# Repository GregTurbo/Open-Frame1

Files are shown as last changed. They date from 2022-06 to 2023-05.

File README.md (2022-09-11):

# Open-Frame1
Open F1 logo stroke mode
An open-source rectangle hardware project for smash, prioritizing ease of assembly and cost.

[Announcement/Overview video](https://youtu.be/RbpOA7Az5DE)

[Example build guide by Crane](https://youtu.be/w4r5CNIimU0)

[Arte's code (pico-rectangle)](https://github.com/JulienBernard3383279/pico-rectangle)

[USB-C to GC cables](https://frame1.gg/collections/all/products/extra-usb-c-to-gamecube-wii-cable)

### Overview
Currently, this project contains the files necessary to create your own Frame1 Light near-equivalent PCB. The files to get this PCB made with parts soldered on are already compiled for you (see: Fabrication Files), but the original schematics are also here if you want to make changes.

The boards are compatible with Rev 1 Heavy and Rev 1/2 Light cases (to be sold in waves on the Frame1.gg website). Switch plate files are included for those who want to design their own case, but full files/guides for creating your own case are planned.

# The Board
whole board
### Overview
In desktop computer terms, the Rapberry Pico is your CPU, and the OF1 PCB is the motherboard. It just feeds power to the Raspberry Pico, routes the USB signal, and connects your switches to the correct pins. 

To accomplish all 3 of these tasks, you will have multiple options. The options you pick will largely depend on budget and level of soldering experience.

## Your Options
- To solder the pico to the board, you can use pin headers or solder the pico straight to the surface. If you use the pin headers, the USB connection will need to be routed via a cable. If you surface mount the pico, you will need to solder in the USB pads on the surface of the pico through the back of the OF1 board (see: Example Builds).
- A surface mount diode can be placed by JLC, but there's also a footprint for a through-hole diode. The through-hole one is easier to solder in if you're doing it yourself. Only use one. Do not populate both.
- You can use Kailh hotswap switches or solder the switches in directly.

Other than the pico, the OF1 board houses 4 main components, and only 2 are mandatory: 
- The main type-c port
- a diode
- a secondary internal type-c port (optional, used to more easily routing the usb signal from the pico to the main port)
- Hotswap sockets
board overview

I would recommend having them assembled via a 3rd party assembly service such as JLC, as type-c ports can be difficult and time-consuming.

## Example Builds

These are examples of the main paths you can take when making a board. All of them assume a board assembled through a 3rd party with at least the main type-c port and diode soldered on already. 

The choice of connecting kailh hotswap sockets vs soldering switches in directly doesn't depend on any of the other assembly choices. The sockets are cheap, and take just as many solder joints to complete as soldering in switches directly. For this reason, I will also be assuming hotswap sockets are be used. It's the option that makes the most sense for the majority of people.

### The Easy Build
This build prioritizes ease of assembly above everything. I highly recommend this path for beginners to soldering. It has the second shortest build time, and the least potential for error. Requires the internal secondary type-c connector.
easy mode

The 3 main steps are:
- Solder in the pico via pin headers (link to that section of the crane vid here)
- Connect a USB micro-b to type-c cable from the pico to the port on the board. (These can be found in 6" lengths on sites like Amazon)
- Solder in hotswap sockets

### The Fast & Cheap build
This build is the cheapest, and assuming no errors, fastest build. Recommended for those with a lot of soldering experience
expert mode

The 3 main steps are:
- Solder the pico on the surface of the OF1 board using the pads and castellated edges on the pico. Alignment is extremely important. You can use the pico's corner holes as a visual guide. Or, you can use something like a matching set of M2 screws and nuts to physically align and hold the board in place (At the time of writing I have not personally tried screws but it should work).
- To connect the USB from the pico to the main board, you need to add solder to these holes on the back of the OF1 board. They make contact with the USB pads on the back of the pico. You may need to pre-tin the test pads before-hand, but your mileage may vary
- Solder in hotswap sockets

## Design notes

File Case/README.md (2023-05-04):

## Open Source Case Options

There are a couple open source case options available when trying to enclose your of1 pcb. These are listed below

# Bjart's OFOF1

https://github.com/rana-sylvatica/OFOF1

# Davy's 3d printable cases

https://www.printables.com/model/394573-openframe1-full-case \
https://www.printables.com/model/394572-openframe1-case-glued

# Ed's 3d printable case

https://www.thingiverse.com/thing:5604960

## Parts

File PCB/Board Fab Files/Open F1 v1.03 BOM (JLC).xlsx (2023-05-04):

Designator | Description | Footprint | LCSC Part Number | Manufacturer Part Number | Comment
D2 | SOD-123 Schottky Diode | SOD-123 | C130880 | MBR120LSF | if you want through hole, populate D1 instead
J2 | USB TYPE-C 24P Receptacle | TYPE-C 24P QCHT | C456013 | TYPE-C 24P QCHT
J5 | USB 2.0 Female Type-C USB 16P | TYPE-C 16P SMD | C2837092 | GT-USB-7010 | Optional
R2, R4 | 5.1K Ohm | _0603 | C881139 |  | If you want through hole, populate R1 and R3 instead

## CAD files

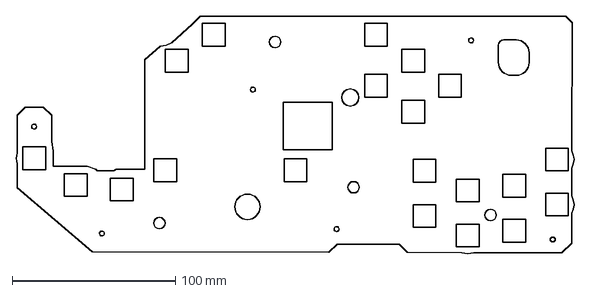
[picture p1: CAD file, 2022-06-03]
Case/Switch Plate.dxf
342.3 x 145.6 mm

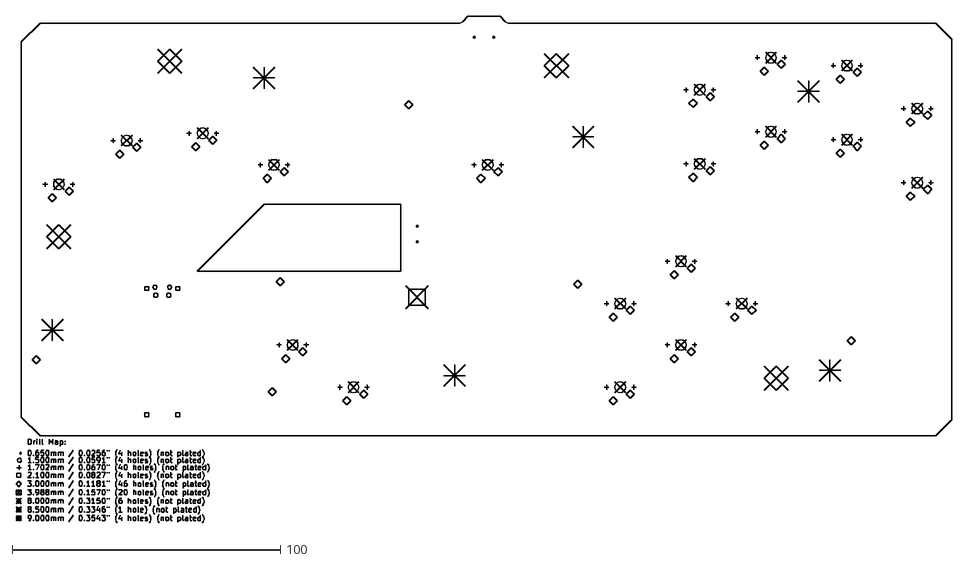
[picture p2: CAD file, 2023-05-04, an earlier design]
PCB/Board Schematics/Kicad_schematics_pico (recommended)/OF1 v1.02/OF1 v1-NPTH-drl_map.dxf
349.0 x 188.8

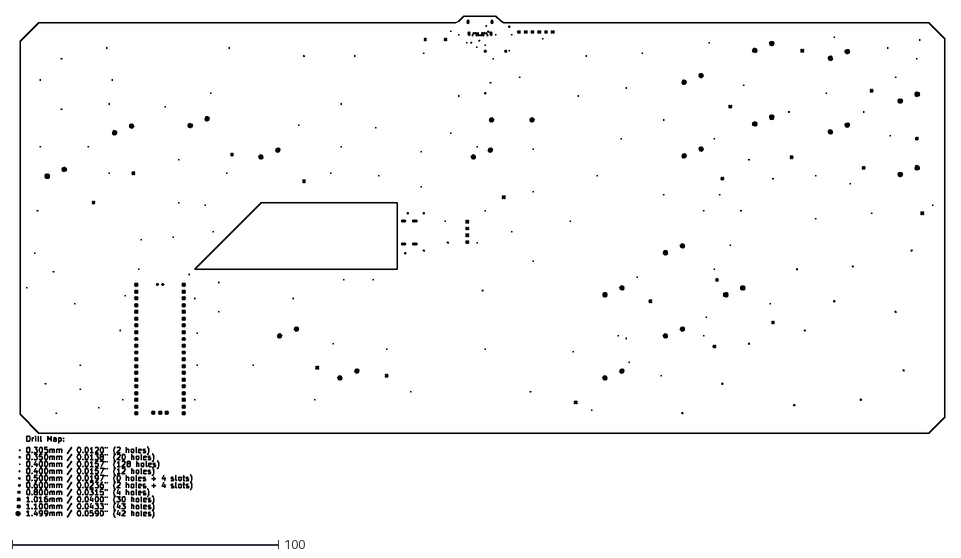
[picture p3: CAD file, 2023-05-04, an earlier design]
PCB/Board Schematics/Kicad_schematics_pico (recommended)/OF1 v1.02/OF1 v1-PTH-drl_map.dxf
348.5 x 188.4

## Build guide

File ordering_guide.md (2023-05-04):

# Open-Frame1 Ordering Guide
First screen you'll upload the fabrication files. Just upload the .zip file located /PCB/Board Fab Files/. At the bottom of this screen JLC asks if you want them to do any smt assembly which you should select.

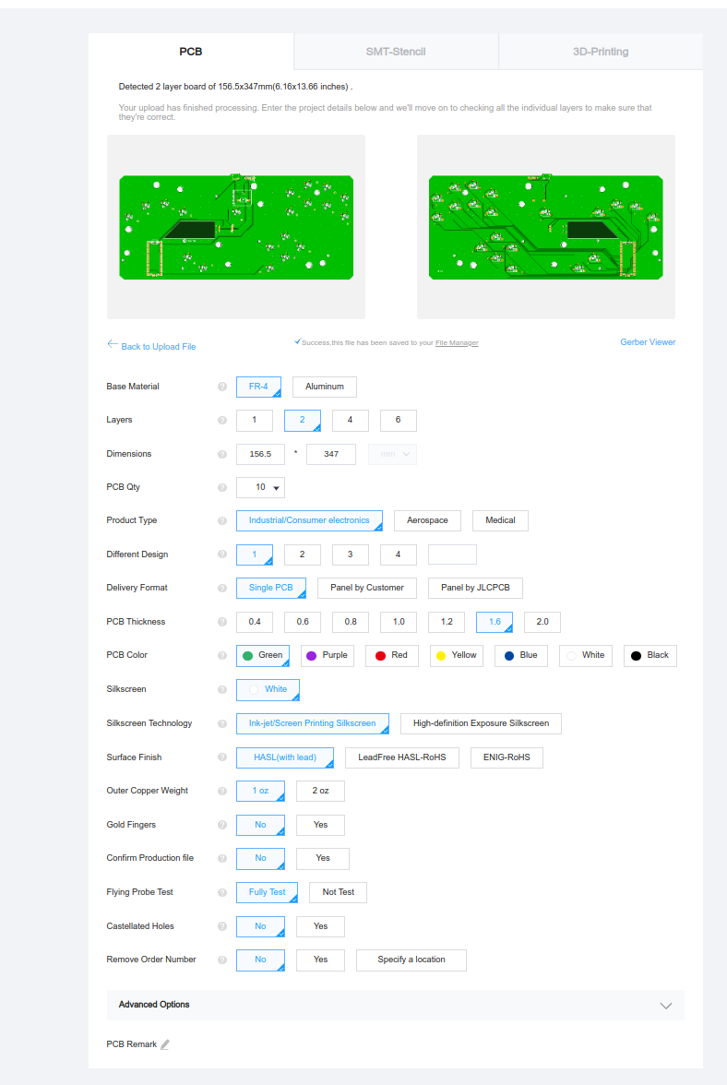
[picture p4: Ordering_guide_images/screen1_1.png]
Screen1_1
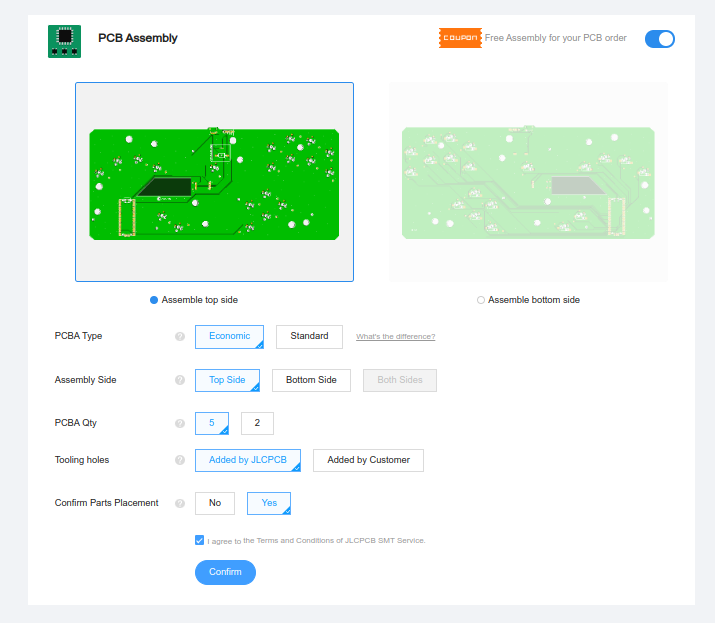
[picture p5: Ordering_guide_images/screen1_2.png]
Screen1_2


Next screen they ask for the BOM (Bill of Materials) spreadsheet and the CPL (tells them where to place the components) spreadsheet. Upload the 2 .xlsx files located in the same folder as the .zip.

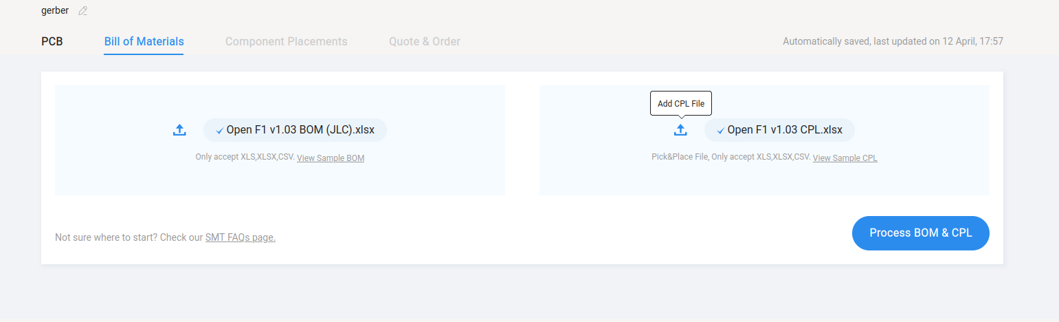
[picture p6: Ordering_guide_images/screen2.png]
Screen2_1


The next screen will ask which components you want them to assemble. The 24 pin connector is pretty much mandatory as you can't do it without a hot air station. The other 4 components are convenient.

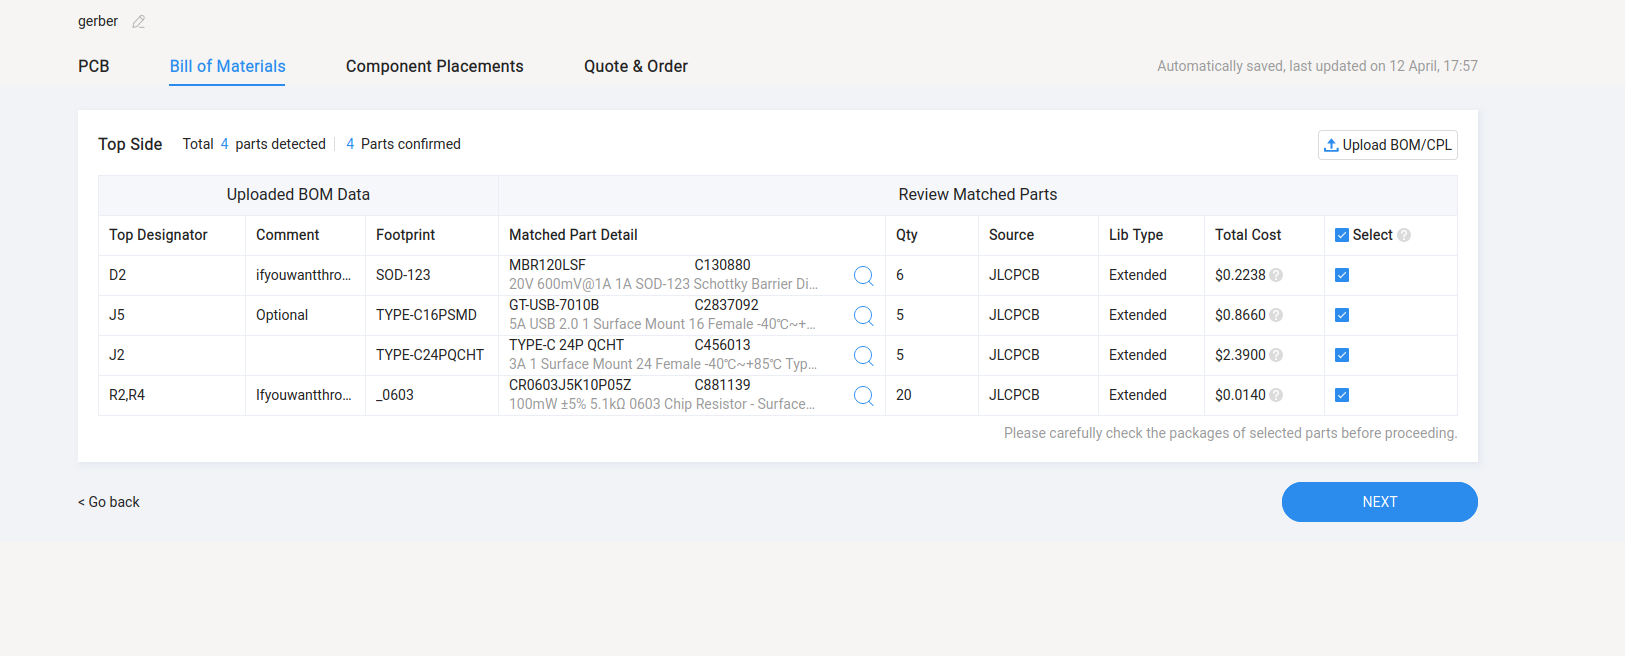
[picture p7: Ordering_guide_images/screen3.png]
Screen3_1


The next screen shows you a preview and from there you should be good to order. Initial renders of the part placement will likely be incorrect. THIS IS OK! If you selected yes to "confirm parts placement" on screen 1 jlc will reach out via email and fix the placements. You will need to confirm that the parts are correct similar to the image included.

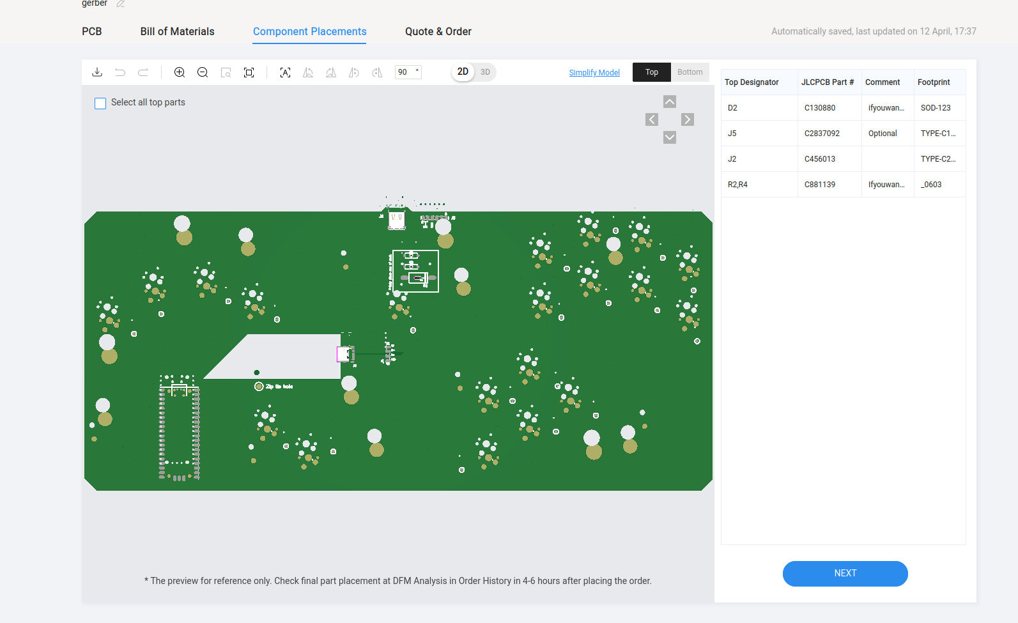
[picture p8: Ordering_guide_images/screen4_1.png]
Screen4_1
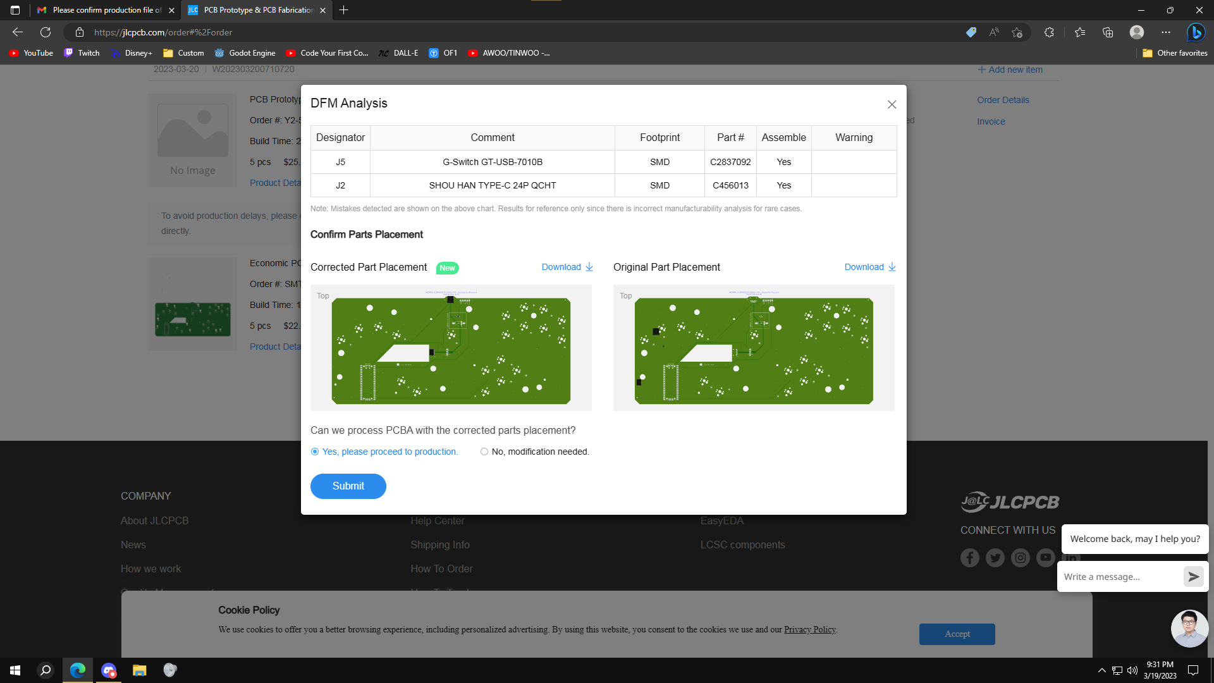
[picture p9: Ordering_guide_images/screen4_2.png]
Screen4_2


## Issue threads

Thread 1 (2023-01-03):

Add instructions for ordering PCBs with assembly to README

Soundtoxin, 2023-01-03:
Thank you for Open-Frame1, it seems very exciting. I think the PCB ordering process is confusing for new users, so some additional info here would be a big help. The build guide video in the readme does not cover this part of the process. I'm hoping to build a few of these controllers and give some to friends in addition to using one myself if I can figure this out.

Something like you see in the README here would be good: https://github.com/rana-sylvatica/circle-keycaps

@rana-sylvatica has put a detailed guide for getting some keycaps from JLC / jlcpcb.com. I would like to use the same site to order some PCBs. The build guide video recommends having them solder on the USB-C port for you since that part is difficult, and possibly also the schottky diode while you're at it, but this process requires a BOM file and CPL file.
For the main target audience (gamers from the FGC) of these controllers, I think this will be difficult and initimidating. Many of them may not have dipped their toes into the DIY electronics world before now. The build guide video does a good job of being applicable to beginners by even recommending a starter soldering iron, solder, and other tools. If we can just improve the PCB ordering part of the process I think a lot more people would be able to actually build these controllers.

I understand that not everyone may order through JLC depending on their geography, but hopefully covering how to get a BOM and CPL file would be enough to help people using other sites as well, and JLC could just serve as an example.

Soundtoxin, 2023-01-04:
I was also referred to the Phob guide for a different controller:

https://github.com/PhobGCC/PhobGCC-doc/blob/main/For_Makers/Phob2_Ordering_Guide.md

However for that controller they've supplied the needed files on their releases page for assembly, so they don't cover how else to get them, and the files would of course be different for the Frame1. I'm starting to get the feeling that the necessary knowledge to complete this is locked away in some Discord. As many people don't use Discord, it would be nice to have it out in the open with everything else.

Soundtoxin, 2023-01-05:
I finally found that the needed files were in the repo, just not the releases page. I would recommend adding:
https://github.com/GregTurbo/Open-Frame1/blob/main/PCB/Board%20Fab%20Files/Open%20F1%20v1%20BOM%20(JLC).xlsx
https://github.com/GregTurbo/Open-Frame1/blob/main/PCB/Board%20Fab%20Files/Open%20F1%20v1%20CPL.xlsx

to the releases page similar to how PhobGCC provides the equivalent files on their releases page.

I'm also finding the process of having a case made rather confusing, but that might be outside the scope of this repo.

I have come across at least two options:
https://github.com/rana-sylvatica/OFOF1
and
https://www.thingiverse.com/thing:5445251

It's not totally clear how many parts actually need to be printed and put together and where to get them all. OFOF1 has standoffs and panels while the thingiverse has "Full_body" and "Full_backplate".
Again I think an additional guide is in order for just wrangling together all the parts and ordering them in the first place. In this case maybe both the above links are valid options, so they could just be explained better within the guide and clarify which parts you need to have printed to have a full enclosure in the end. My thoughts at this point are that I may just need to get most of what I think I need in-hand and then maybe during assembly I'll realize if something is missing, and then I'll end up waiting a few more days to get any parts I may be missing.
A guide could also discuss pros and cons of resin vs nylon for some of these parts and ways to make some things more affordable. I was a bit shocked at the shipping costs from JLC PCB (I'm in the US). For the PCBs I was paying almost exactly as much for shipping as I was for the boards. There were some cheaper shipping options but none significantly cheaper, so it didn't really seem worth a possible worse experience than DHL. To make matters worse, you can't order 3D prints and PCBs together from JLC, so I would have to eat that massive shipping cost a second time. I've held off ordering the 3D prints for now in case I can find a cheaper way to have those parts made (and because it's still unclear for sure which parts I do need to have made).

Soundtoxin, 2023-02-06:
Just an update, the linked thingiverse case in the previous post has another (newer) variant that you can print at home in smaller pieces and then glue together. I've had mostly pretty good luck with using an Ender 3 v2 with PLA+ filament and then glueing with superglue. I would recommend this version as it can be printed without supports and is the most up-to-date version of the case.

https://www.thingiverse.com/thing:5632408

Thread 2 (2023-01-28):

Different MCU and MCU placement for future revisions

Soundtoxin, 2023-01-28:
I've been looking into the Flatbox rev5[0] recently and thinking they did certain things better than the Open-Frame1 board. In particular they chose an MCU with a USB-C port and put it in the top middle of the board so you can just plug right into it. No hassle of soldering a USB-C port or ordering a board with assembly. This is similar to how a lot of mechanical keyboard builds are handled as well. They use the RP2040-Zero[1], which is somewhat niche, I could only find it on waveshare and not adafruit. There are some other RP2040-based boards with USB-C boards, though, such as the Feather[2] boards from adafruit. Something like that might simplify the build a lot. It feels kinda jank having a cable in there to reroute the USB, and it kinda bulges and makes it hard to get the case together.

The Feather board I linked as an example does cost more than the Pi Pico currently used, however if you add in the cost of a cable to go from microUSB B to USB-C that you won't need anymore, it doesn't look so bad.

It's possible I'm overlooking part of the design. Maybe the placement is to best fit an optional Brook add-on board without getting in the way of the buttons. I know there's a label saying you can use some of the holes for a zip-tie. I haven't done any of that in my builds so far.

[0] https://github.com/jfedor2/flatbox/tree/master/hardware-rev5
[1] https://www.waveshare.com/rp2040-zero.htm
[2] https://www.adafruit.com/product/4884

Soundtoxin, 2023-02-10:
Regarding placement, I think it's also worth considering designing the PCB to have the controller on the bottom instead of the top of the PCB. This would give easier access to the BOOTSEL button in case of flashing bad firmware and not being able to use a button combo to get into this mode. Currently (at least with the [case](https://www.thingiverse.com/thing:5632408) I used) you have to remove every single switch, remove the bottom cover, and pull out the PCB if you need to get at the BOOTSEL button. If the microcontroller were on the bottom instead, you'd only need to remove the bottom cover to get at the buttons, and you could leave your switches in.

Soundtoxin, 2023-06-15:
There's also a TP6 pad on the bottom of the Pico you can short to ground which can act as BOOTSEL. A couple well-placed holes in the Open-Frame1 PCB, or even better, a place to solder a new button to those bits for bottom-access would be another good option.
Recently I keep having some of my buttons (mostly the up button on the far right) pop out (using kailh hotswap sockets) during play or transport, and there's a decent chance of the pins bending when re-inserting. I don't want to solder or glue in these switches since that would lock off easy access to BOOTSEL in case of a firmware emergency. If I had more convenient access to that mode from the bottom, I would be able to put a dab of hot glue or something on my switch pins from the bottom to hold them in better without worrying that I'll have to remove every switch later to fix the firmware (not hypothetical, by the way, I put GP2040-CE on an Open-Frame1 once to see if PS3/4 support was better than in HayBox and the button mappings were a mess so I couldn't figure out what to press to flash it again and had to tear it apart).

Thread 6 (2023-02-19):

Alternate links for USB-C to GC cable

Soundtoxin, 2023-02-19:
I think we need an alternate source for the cables in the readme. I ordered one from the Frame1 site over a month ago, and have heard basically nothing. They show as in-stock, so I assumed they were already made and would just be shipped out. Not sure what the deal is. I managed to get a cable from the B0xx site in under a week (ordered fewer *and* they cost a little more, though), and they also have the USB-C to N64 cables, so they should be listed as a source instead or additionally. I also think a guide for making your own cables would be good to have linked in the readme to reduce these points of failure in sourcing such an important part. I don't know of a good guide, hopefully someone else does. Otherwise one may need to be written/recorded.

GregTurbo, 2023-02-19:
Your order includes 2 things that are not currently shipping (brook installation kits that are only for the soon-to-be released Frame1 wave). Your order would have shipped weeks ago otherwise

Soundtoxin, 2023-02-19:
Thank you for the additional info, Greg. I still really do think it may be worth listing multiple sources / DIY methods for the cables in the future (so not sure the issue should be closed), but I'm glad to have cleared up my particular case now.

Closed 2023-02-19.

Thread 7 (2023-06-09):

Could I use a wire instead of a Schottky DIODE?

zerinsakech, 2023-06-09:
The instructions make it seem like a Diode is needed regardless whether you use the additional Connections (for direct GameCube controller port I assume?) Since most case designs for the Open1 don't seem to include this extra port, and it's cheaper/easier to make a USB C to GameCube cable instead of designing a case with the port, can we just wire up a solid wire (0 ohm) instead of a DIODE? I'm trying to save money and costs so wondering if this is a good alternate instruction to add to the Readme?

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

GregTurbo, 2023-06-09:
There is no second port, the usb-c connector handles USB or GCC connections with their respective cables. The unpopulated headed on the right there is just for the sake of mods or troubleshooting.

If you're ONLY ever going to use USB, and don't plan on using a GameCube connection, DO NOT use a wire. Instead, just don't populate the diode at all. USB will work fine and you can always add the diode later anyway

zerinsakech, 2023-06-09:
Thanks for the clarification!

Closed 2023-06-09.

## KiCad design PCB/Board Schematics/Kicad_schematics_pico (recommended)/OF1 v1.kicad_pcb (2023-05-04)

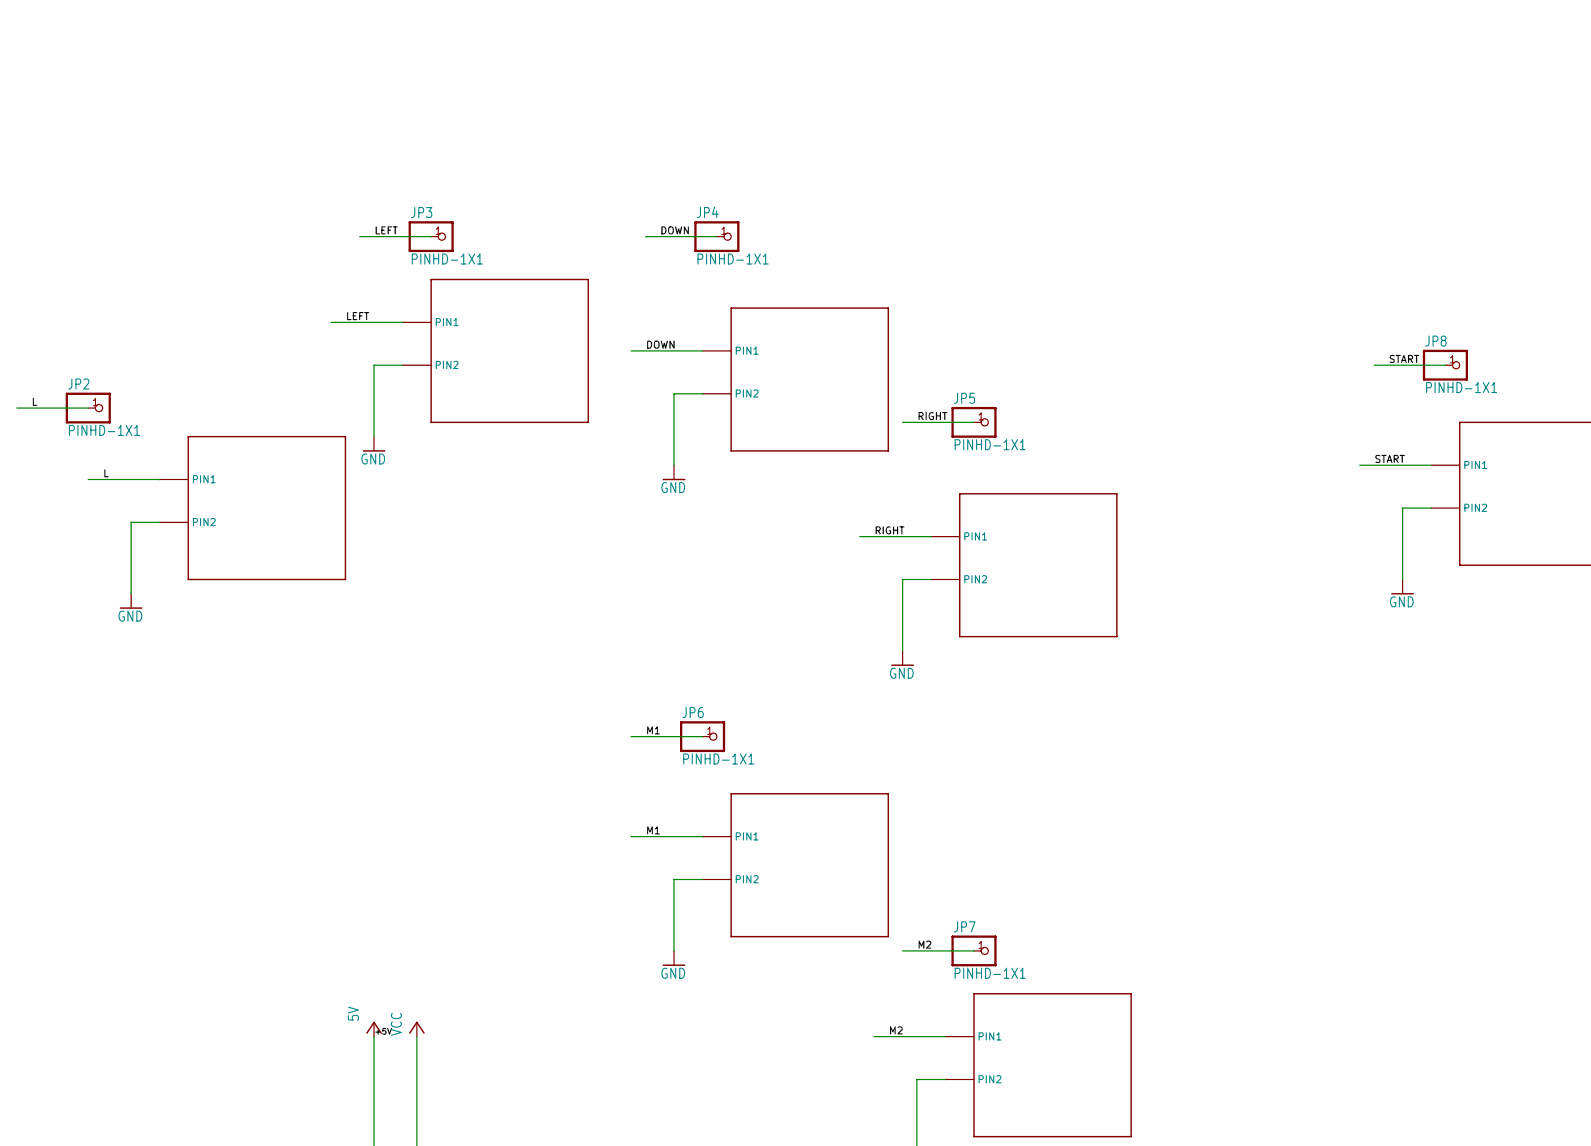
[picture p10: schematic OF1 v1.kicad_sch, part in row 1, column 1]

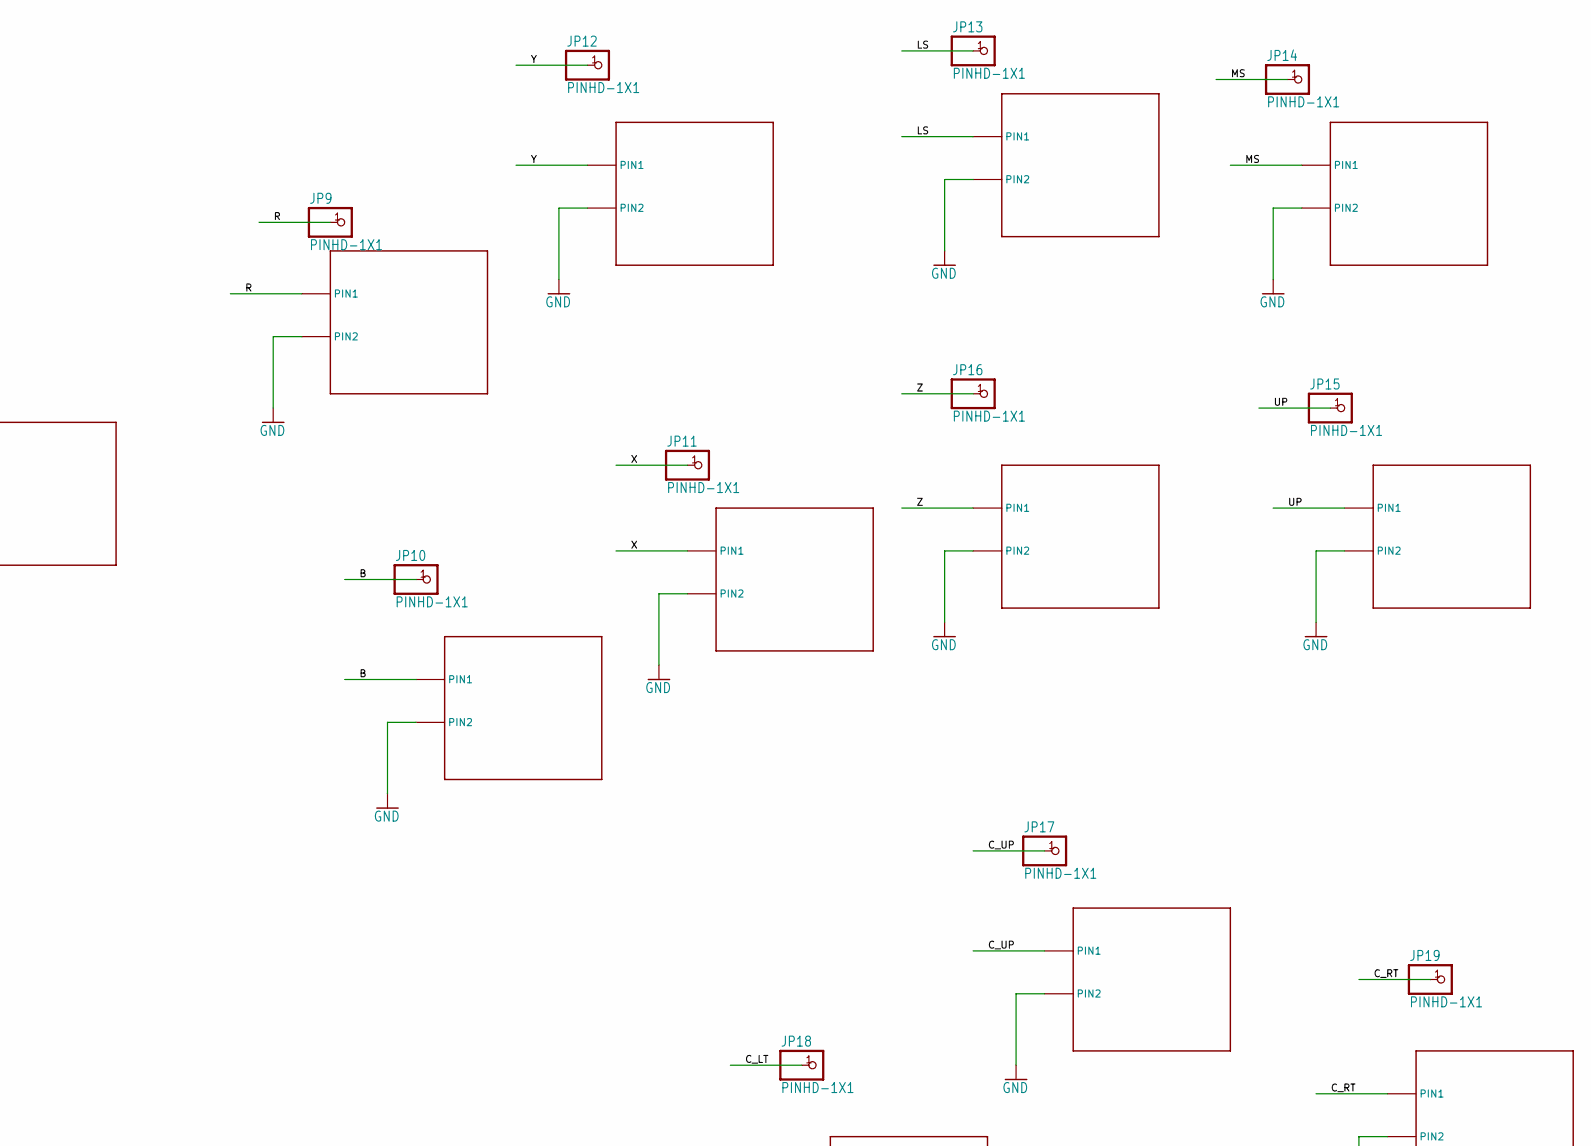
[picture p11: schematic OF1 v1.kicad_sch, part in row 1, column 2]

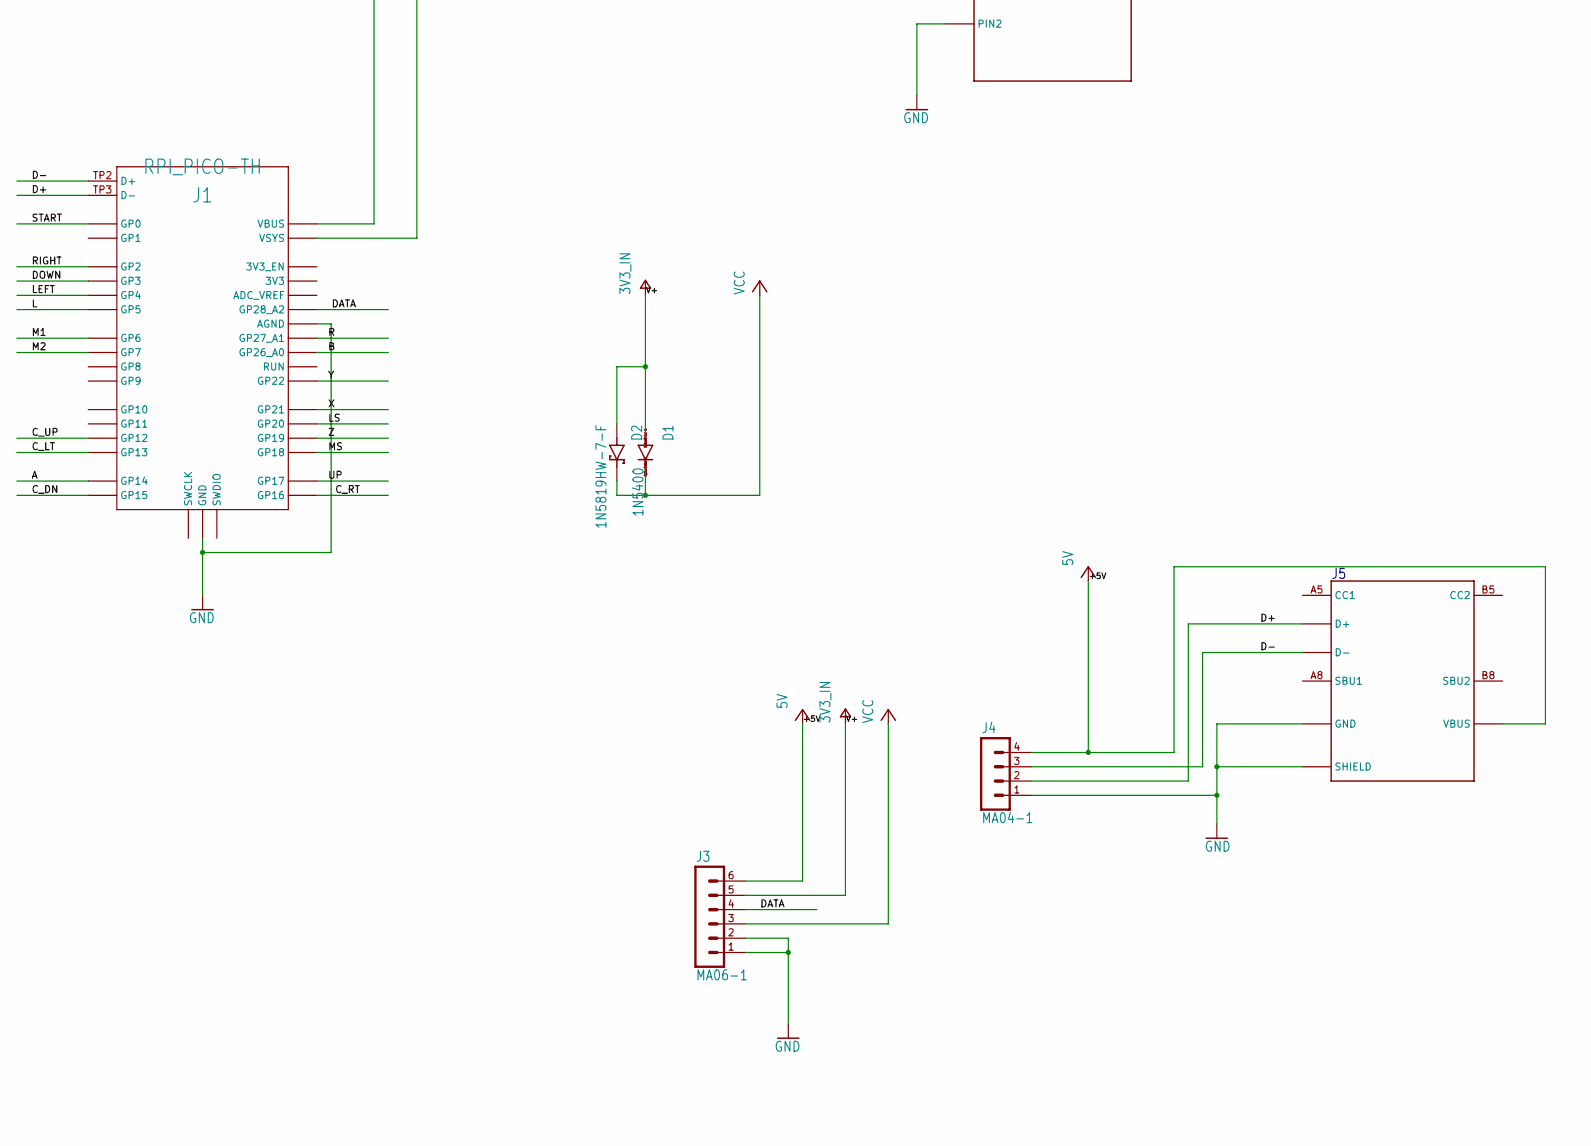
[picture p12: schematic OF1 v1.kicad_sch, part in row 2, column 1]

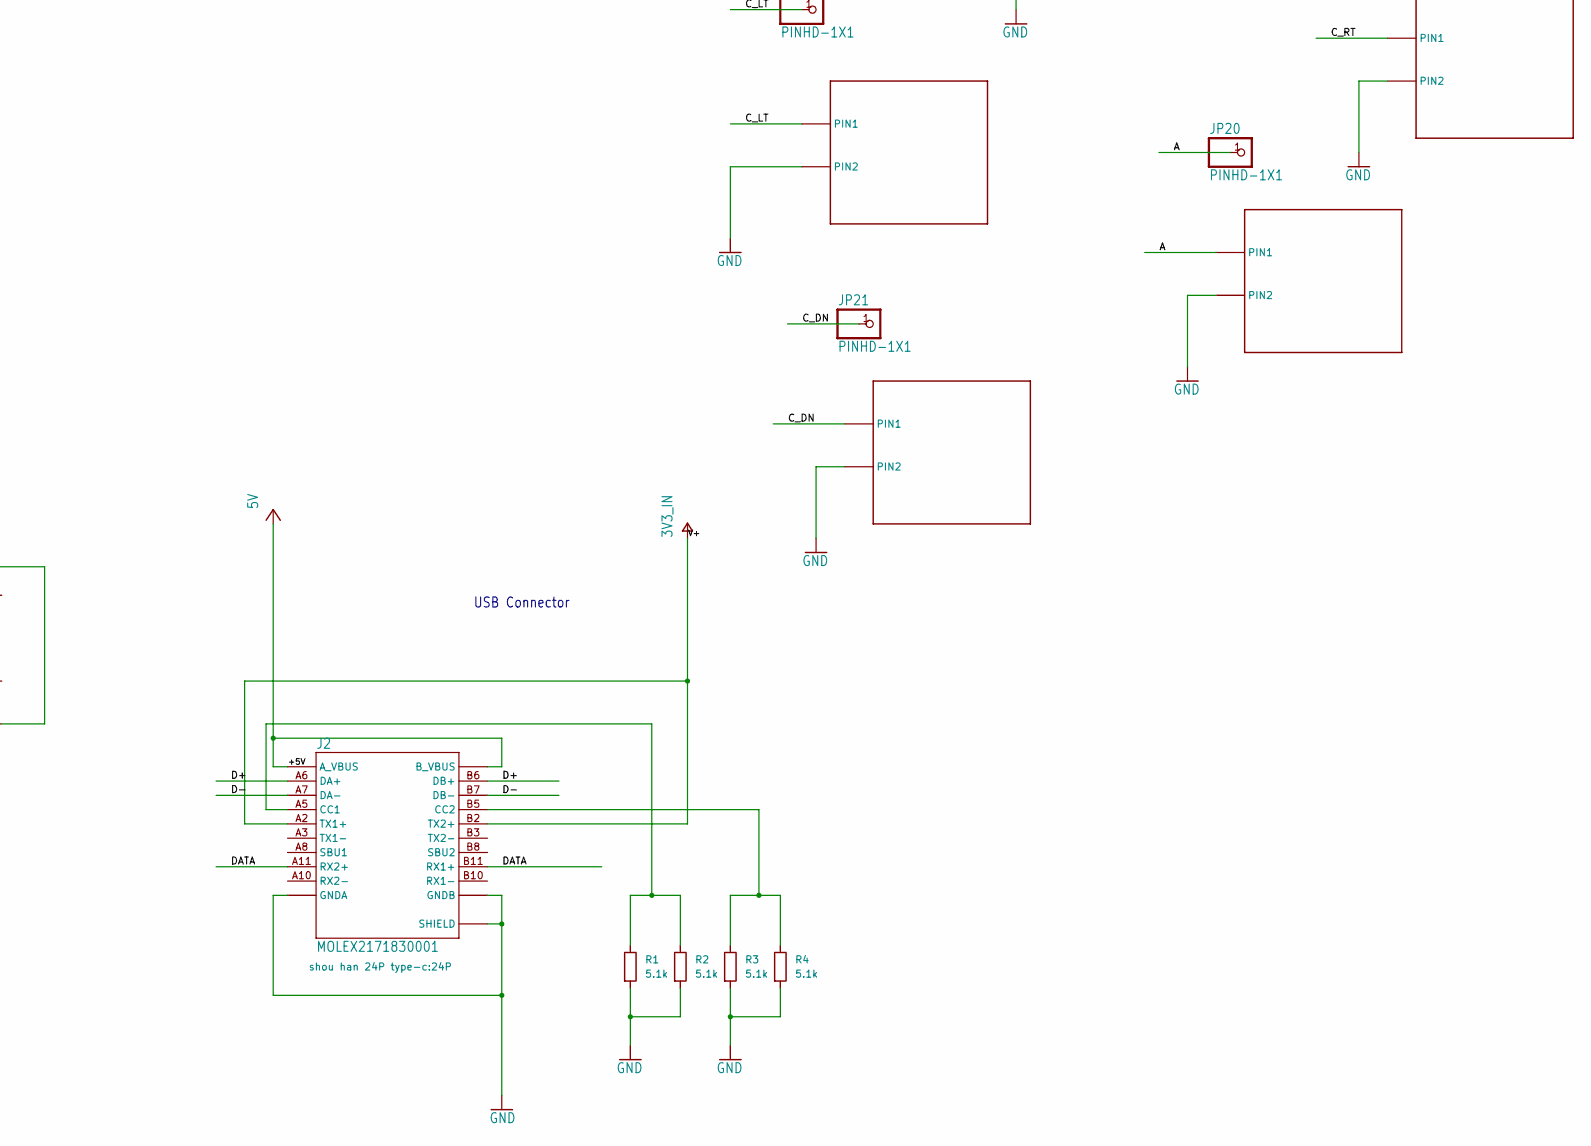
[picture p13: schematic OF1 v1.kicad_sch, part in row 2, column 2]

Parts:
D1: 1N5400; DO201-15
D2: 1N5819HW-7-F; SOD3715X145N
J1: RPI_PICO-TH; RPI_PICO_TH
J2: MOLEX2171830001; 24P
J3: MA06-1
J4: MA04-1
J5: GT-USB-7010; 16P
JP2, JP3, JP4, JP5, JP6, JP7, JP8, JP9, JP10, JP11, JP12, JP13, JP14, JP15, JP16, JP17, JP18, JP19, JP20, JP21: PINHD-1X1; 1X01
R1, R3: 5.1k; R_Axial_DIN0207_L6.3mm_D2.5mm_P7.62mm_Horizontal
R2, R4: 5.1k; R_0603_1608Metric
U$1, U$2, U$4, U$5, U$6, U$7, U$8, U$9, U$10, U$11, U$12, U$13, U$14, U$15, U$16, U$17, U$18, U$19, U$20, U$21: MX-B; MX-BOTH

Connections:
+5V: J1.VBUS, J2.A4 (A_VBUS), J2.A9 (A_VBUS), J2.B4 (B_VBUS), J2.B9 (B_VBUS), J3.6, J4.4, J5.A4/B9 (VBUS), J5.B4/A9 (VBUS)
/A: J1.GP14, JP20.1, U$20.P$2 (PIN1), U$20.P$3 (PIN1)
/B: J1.GP26_A0, JP10.1, U$13.P$2 (PIN1), U$13.P$3 (PIN1)
/C_DN: J1.GP15, JP21.1, U$21.P$2 (PIN1), U$21.P$3 (PIN1)
/C_LT: J1.GP13, JP18.1, U$18.P$2 (PIN1), U$18.P$3 (PIN1)
/C_RT: J1.GP16, JP19.1, U$19.P$2 (PIN1), U$19.P$3 (PIN1)
/C_UP: J1.GP12, JP17.1, U$17.P$2 (PIN1), U$17.P$3 (PIN1)
/D+: J1.TP3 (D-), J2.A6 (DA+), J2.B6 (DB+), J4.2, J5.A6 (D+), J5.B6 (D+)
/D-: J1.TP2 (D+), J2.A7 (DA-), J2.B7 (DB-), J4.3, J5.A7 (D-), J5.B7 (D-)
/DATA: J1.GP28_A2, J2.A11 (RX2+), J2.B11 (RX1+), J3.4
/DOWN: J1.GP3, JP4.1, U$4.P$2 (PIN1), U$4.P$3 (PIN1)
/L: J1.GP5, JP2.1, U$1.P$2 (PIN1), U$1.P$3 (PIN1)
/LEFT: J1.GP4, JP3.1, U$2.P$2 (PIN1), U$2.P$3 (PIN1)
/LS: J1.GP20, JP13.1, U$11.P$2 (PIN1), U$11.P$3 (PIN1)
/M1: J1.GP6, JP6.1, U$6.P$2 (PIN1), U$6.P$3 (PIN1)
/M2: J1.GP7, JP7.1, U$7.P$2 (PIN1), U$7.P$3 (PIN1)
/MS: J1.GP18, JP14.1, U$12.P$2 (PIN1), U$12.P$3 (PIN1)
/R: J1.GP27_A1, JP9.1, U$9.P$2 (PIN1), U$9.P$3 (PIN1)
/RIGHT: J1.GP2, JP5.1, U$5.P$2 (PIN1), U$5.P$3 (PIN1)
/START: J1.GP0, JP8.1, U$8.P$2 (PIN1), U$8.P$3 (PIN1)
/UP: J1.GP17, JP15.1, U$16.P$2 (PIN1), U$16.P$3 (PIN1)
/X: J1.GP21, JP11.1, U$14.P$2 (PIN1), U$14.P$3 (PIN1)
/Y: J1.GP22, JP12.1, U$10.P$2 (PIN1), U$10.P$3 (PIN1)
/Z: J1.GP19, JP16.1, U$15.P$2 (PIN1), U$15.P$3 (PIN1)
GND: J1.AGND, J1.GND@1 (GND), J1.GND@2 (GND), J1.GND@3 (GND), J1.GND@4 (GND), J1.GND@5 (GND), J1.GND@6 (GND), J1.GND@7 (GND), J1.GND@8 (GND), J2.A1 (GNDA), J2.A12 (GNDA), J2.B1 (GNDB), J2.B12 (GNDB), J2.SHIELD1 (SHIELD), J2.SHIELD2 (SHIELD), J2.SHIELD3 (SHIELD), J2.SHIELD4 (SHIELD), J3.1, J3.2, J4.1, J5.A1/B12 (GND), J5.B1/A12 (GND), J5.SHIELD1 (SHIELD), J5.SHIELD2 (SHIELD), J5.SHIELD3 (SHIELD), J5.SHIELD4 (SHIELD), R1.2, R2.2, R3.2, R4.2, U$1.P$1 (PIN2), U$1.P$4 (PIN2), U$2.P$1 (PIN2), U$2.P$4 (PIN2), U$4.P$1 (PIN2), U$4.P$4 (PIN2), U$5.P$1 (PIN2), U$5.P$4 (PIN2), U$6.P$1 (PIN2), U$6.P$4 (PIN2), U$7.P$1 (PIN2), U$7.P$4 (PIN2), U$8.P$1 (PIN2), U$8.P$4 (PIN2), U$9.P$1 (PIN2), U$9.P$4 (PIN2), U$10.P$1 (PIN2), U$10.P$4 (PIN2), U$11.P$1 (PIN2), U$11.P$4 (PIN2), U$12.P$1 (PIN2), U$12.P$4 (PIN2), U$13.P$1 (PIN2), U$13.P$4 (PIN2), U$14.P$1 (PIN2), U$14.P$4 (PIN2), U$15.P$1 (PIN2), U$15.P$4 (PIN2), U$16.P$1 (PIN2), U$16.P$4 (PIN2), U$17.P$1 (PIN2), U$17.P$4 (PIN2), U$18.P$1 (PIN2), U$18.P$4 (PIN2), U$19.P$1 (PIN2), U$19.P$4 (PIN2), U$20.P$1 (PIN2), U$20.P$4 (PIN2), U$21.P$1 (PIN2), U$21.P$4 (PIN2)
unnamed: J2.A5 (CC1), R1.1, R2.1
unnamed: J2.B5 (CC2), R3.1, R4.1
V+: D1.A, D2.A, J2.A2 (TX1+), J2.B2 (TX2+), J3.5
VCC: D1.C, D2.C (K), J1.VSYS, J3.3

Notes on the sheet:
USB Connector

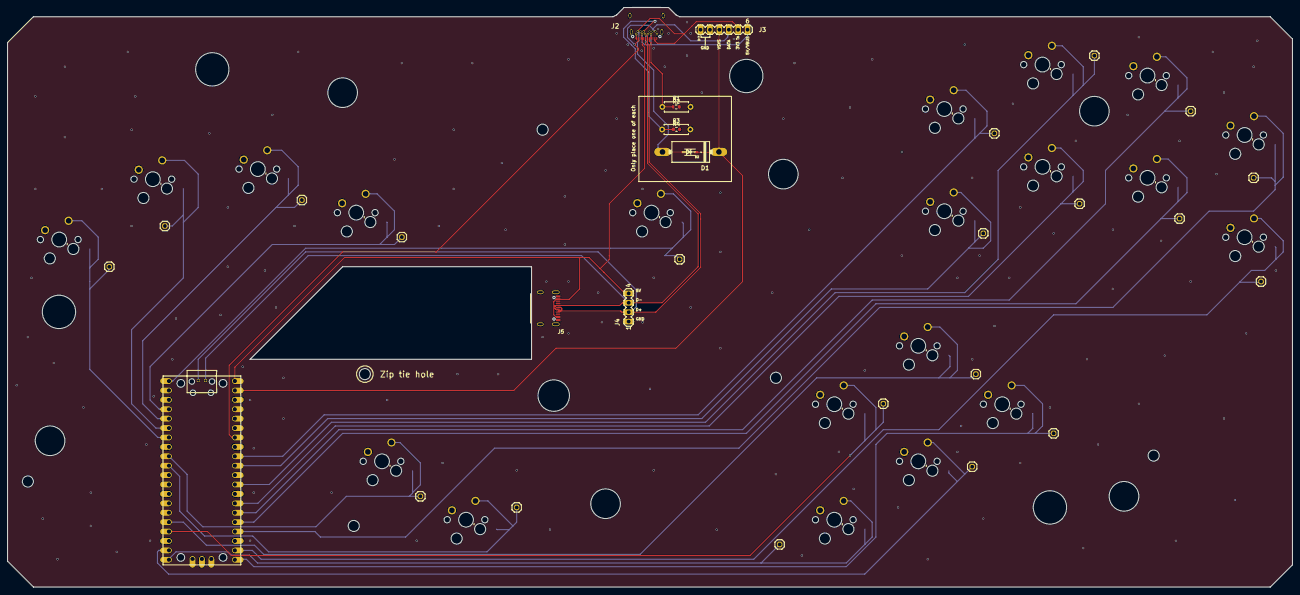
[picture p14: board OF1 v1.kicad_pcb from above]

Board: 2 copper layers, 347.0 x 156.5 mm, 68 parts (0 on the bottom side), 29 nets.

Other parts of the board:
@HOLE0, @HOLE1, @HOLE2, @HOLE3, @HOLE4, @HOLE5, @HOLE6, @HOLE7, @HOLE8, @HOLE9, @HOLE10, @HOLE11, @HOLE12, @HOLE13, @HOLE14, @HOLE15, @HOLE16: (no value)

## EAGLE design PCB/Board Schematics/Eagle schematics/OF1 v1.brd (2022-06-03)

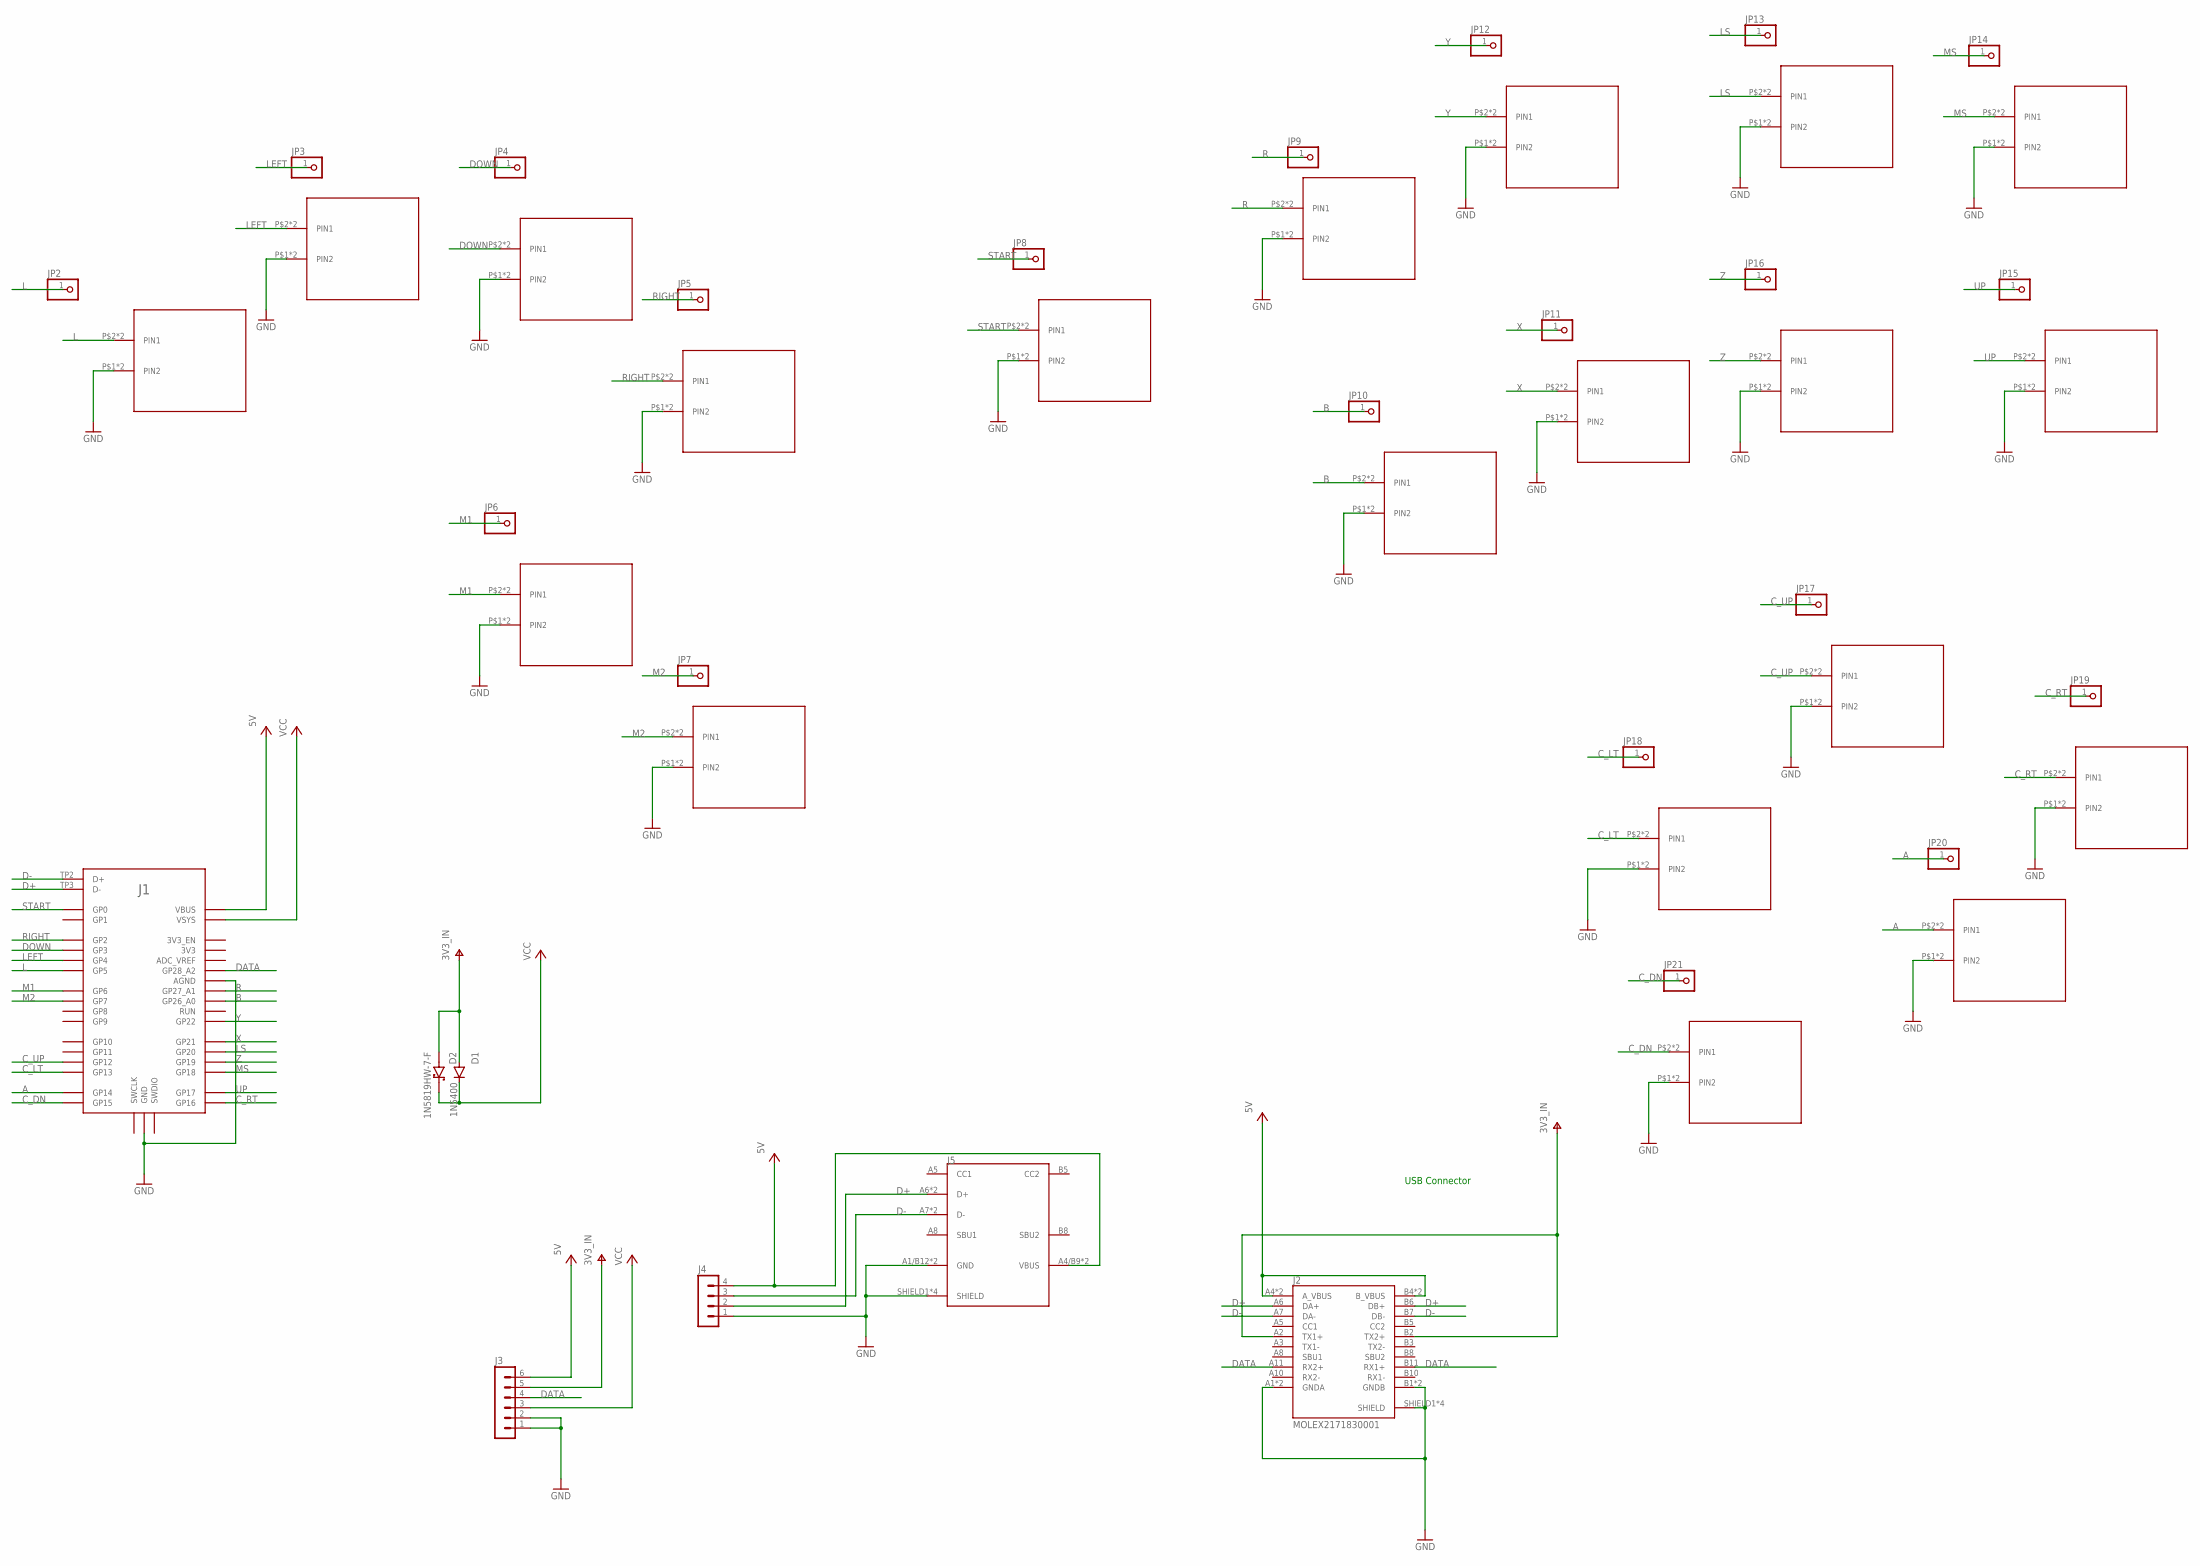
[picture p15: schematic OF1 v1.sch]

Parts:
D1: 1N5400; DO201-15
D2: 1N5819HW-7-F; SOD3715X145N
J1: RPI_PICO-TH; RPI_PICO_TH
J2: MOLEX2171830001; 24P
J3: MA06-1
J4: MA04-1
J5: GT-USB-7010ASV; 16P
JP2, JP3, JP4, JP5, JP6, JP7, JP8, JP9, JP10, JP11, JP12, JP13, JP14, JP15, JP16, JP17, JP18, JP19, JP20, JP21: PINHD-1X1; 1X01
U$1, U$2, U$4, U$5, U$6, U$7, U$8, U$9, U$10, U$11, U$12, U$13, U$14, U$15, U$16, U$17, U$18, U$19, U$20, U$21: MX-B; MX-BOTH

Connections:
+5V: J1.VBUS, J2.A4 (A_VBUS), J2.A9 (A_VBUS), J2.B4 (B_VBUS), J2.B9 (B_VBUS), J3.6, J4.4, J5.A4/B9 (VBUS), J5.B4/A9 (VBUS)
A: J1.GP14, JP20.1, U$20.P$2 (PIN1), U$20.P$3 (PIN1)
B: J1.GP26_A0, JP10.1, U$13.P$2 (PIN1), U$13.P$3 (PIN1)
C_DN: J1.GP15, JP21.1, U$21.P$2 (PIN1), U$21.P$3 (PIN1)
C_LT: J1.GP13, JP18.1, U$18.P$2 (PIN1), U$18.P$3 (PIN1)
C_RT: J1.GP16, JP19.1, U$19.P$2 (PIN1), U$19.P$3 (PIN1)
C_UP: J1.GP12, JP17.1, U$17.P$2 (PIN1), U$17.P$3 (PIN1)
D+: J1.TP3 (D-), J2.A6 (DA+), J2.B6 (DB+), J4.2, J5.A6 (D+), J5.B6 (D+)
D-: J1.TP2 (D+), J2.A7 (DA-), J2.B7 (DB-), J4.3, J5.A7 (D-), J5.B7 (D-)
DATA: J1.GP28_A2, J2.A11 (RX2+), J2.B11 (RX1+), J3.4
DOWN: J1.GP3, JP4.1, U$4.P$2 (PIN1), U$4.P$3 (PIN1)
GND: J1.AGND, J1.GND@1 (GND), J1.GND@2 (GND), J1.GND@3 (GND), J1.GND@4 (GND), J1.GND@5 (GND), J1.GND@6 (GND), J1.GND@7 (GND), J1.GND@8 (GND), J2.A1 (GNDA), J2.A12 (GNDA), J2.B1 (GNDB), J2.B12 (GNDB), J2.SHIELD1 (SHIELD), J2.SHIELD2 (SHIELD), J2.SHIELD3 (SHIELD), J2.SHIELD4 (SHIELD), J3.1, J3.2, J4.1, J5.A1/B12 (GND), J5.B1/A12 (GND), J5.SHIELD1 (SHIELD), J5.SHIELD2 (SHIELD), J5.SHIELD3 (SHIELD), J5.SHIELD4 (SHIELD), U$1.P$1 (PIN2), U$1.P$4 (PIN2), U$2.P$1 (PIN2), U$2.P$4 (PIN2), U$4.P$1 (PIN2), U$4.P$4 (PIN2), U$5.P$1 (PIN2), U$5.P$4 (PIN2), U$6.P$1 (PIN2), U$6.P$4 (PIN2), U$7.P$1 (PIN2), U$7.P$4 (PIN2), U$8.P$1 (PIN2), U$8.P$4 (PIN2), U$9.P$1 (PIN2), U$9.P$4 (PIN2), U$10.P$1 (PIN2), U$10.P$4 (PIN2), U$11.P$1 (PIN2), U$11.P$4 (PIN2), U$12.P$1 (PIN2), U$12.P$4 (PIN2), U$13.P$1 (PIN2), U$13.P$4 (PIN2), U$14.P$1 (PIN2), U$14.P$4 (PIN2), U$15.P$1 (PIN2), U$15.P$4 (PIN2), U$16.P$1 (PIN2), U$16.P$4 (PIN2), U$17.P$1 (PIN2), U$17.P$4 (PIN2), U$18.P$1 (PIN2), U$18.P$4 (PIN2), U$19.P$1 (PIN2), U$19.P$4 (PIN2), U$20.P$1 (PIN2), U$20.P$4 (PIN2), U$21.P$1 (PIN2), U$21.P$4 (PIN2)
L: J1.GP5, JP2.1, U$1.P$2 (PIN1), U$1.P$3 (PIN1)
LEFT: J1.GP4, JP3.1, U$2.P$2 (PIN1), U$2.P$3 (PIN1)
LS: J1.GP20, JP13.1, U$11.P$2 (PIN1), U$11.P$3 (PIN1)
M1: J1.GP6, JP6.1, U$6.P$2 (PIN1), U$6.P$3 (PIN1)
M2: J1.GP7, JP7.1, U$7.P$2 (PIN1), U$7.P$3 (PIN1)
MS: J1.GP18, JP14.1, U$12.P$2 (PIN1), U$12.P$3 (PIN1)
R: J1.GP27_A1, JP9.1, U$9.P$2 (PIN1), U$9.P$3 (PIN1)
RIGHT: J1.GP2, JP5.1, U$5.P$2 (PIN1), U$5.P$3 (PIN1)
START: J1.GP0, JP8.1, U$8.P$2 (PIN1), U$8.P$3 (PIN1)
UP: J1.GP17, JP15.1, U$16.P$2 (PIN1), U$16.P$3 (PIN1)
V+: D1.A, D2.A, J2.A2 (TX1+), J2.B2 (TX2+), J3.5
VCC: D1.C, D2.C (K), J1.VSYS, J3.3
X: J1.GP21, JP11.1, U$14.P$2 (PIN1), U$14.P$3 (PIN1)
Y: J1.GP22, JP12.1, U$10.P$2 (PIN1), U$10.P$3 (PIN1)
Z: J1.GP19, JP16.1, U$15.P$2 (PIN1), U$15.P$3 (PIN1)

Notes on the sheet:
USB Connector

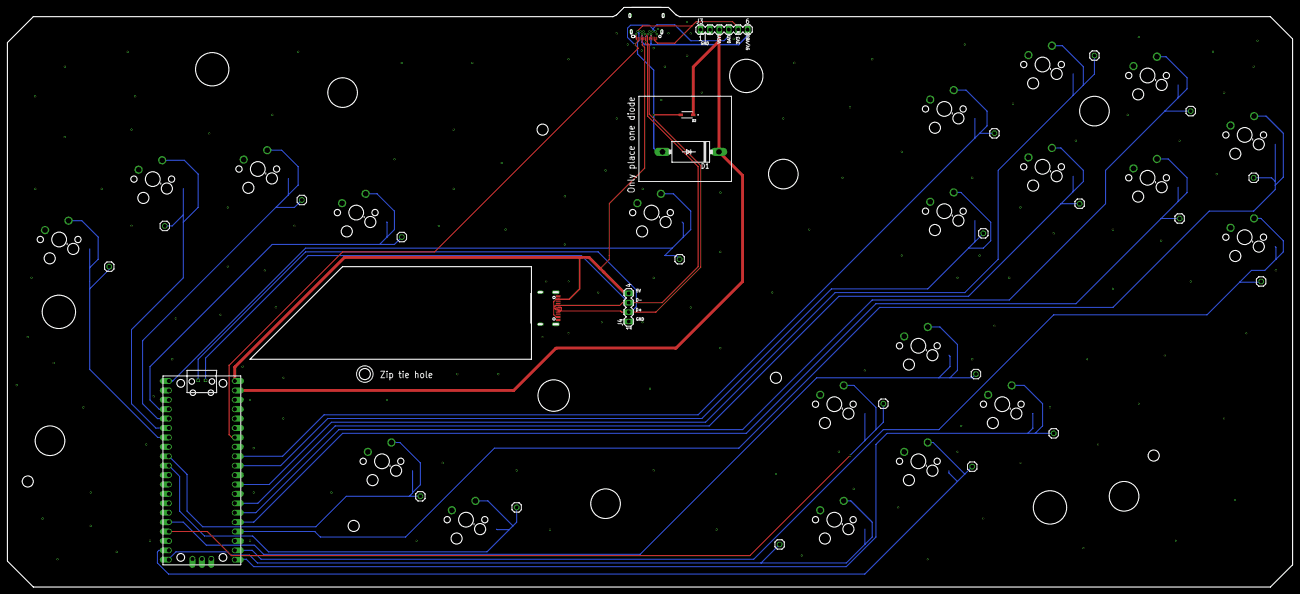
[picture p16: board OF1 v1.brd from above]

Board: 2 copper layers, 347.0 x 156.5 mm, 47 parts (0 on the bottom side), 27 nets.

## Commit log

2022-06-17 Fixed the BOM
    [Open F1 v1 BOM (JLC).xlsx]
2022-08-11 Added Kicad version
    Moved to Kicad to avoid slotted hole issues with JLC
    [OF1 v1-B_Cu.gbl, OF1 v1-B_Cu.gbr, OF1 v1-B_Mask.gbr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]
2022-10-10 Wip COMMIT
    [OF1 v1-B_Cu.gbl, OF1 v1-B_Cu.gbr, OF1 v1-B_Mask.gbr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]
2022-10-11 adding usbc support to the pcb. Updating fab files to reflect
    [OF1 v1-B_Cu.gbl, OF1 v1-B_Cu.gbr, OF1 v1-B_Mask.gbr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]
2023-02-01 checked to make sure all files are good
    [OF1 v1-B_Cu.gbr, OF1 v1-B_Mask.gbr, OF1 v1-B_Paste.gbr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]
2023-04-12 added ordering guide
    [OF1 v1-B_Cu.gbl, OF1 v1-B_Mask.gbs, OF1 v1-B_Paste.gbp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]
2023-04-12 adding updated fab files
    [OF1 v1-B_Cu.gbl, OF1 v1-B_Mask.gbs, OF1 v1-B_Paste.gbp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]
2023-04-13 added case Read Me
2024-02-11 1.04, new hotswap socket footprint
    [OF1 v1-B_Cu.gbl, OF1 v1-B_Mask.gbs, OF1 v1-B_Paste.gbp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]
